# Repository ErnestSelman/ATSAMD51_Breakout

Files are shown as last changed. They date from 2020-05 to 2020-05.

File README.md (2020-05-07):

# ATSAMD51_Breakout
Similar to SparkFun Thing Plus but without battery charging and leaving USB and FLASH Memory in the same pins. All other pins are accessible. I also added a connector for the PICKit4.

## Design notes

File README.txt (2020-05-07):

Notes:
-Board Dimentions: 61.180 mm x 30.365 mm
-Drill sizes were chosen to be one of your free sizes, if any of them is not exactly one of the free sizes then it can be changed to nearest free size.
-PTH Holes sizes are finish hole sizes.

-Drill files:
	-drill_npth.xln
	-dril_pth.xln
-Gerber files included:
	-copper_bottom.gbr
	-copper_top.gbr
	-profile.gbr
	-silkscreen_top.gbr
	-soldermask_bottom.gbr
	-soldermask_top.gbr
-Aditional Files:
	-gerber_job.gbrjob
	-README.txt
	-SAMD51_Breakout.brd
	-SAMD51_Breakout.sch

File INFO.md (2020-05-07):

# ATSAMD51_Breakout
Similar to SparkFun Thing Plus but without battery charging and leaving USB and FLASH Memory in the same pins. All other pins are accessible. I also added a connector for the PICKit4 programmer/debugger. 
You could follow SparkFun Thing Plus tutorial and program their bootloader. It should work the same as theirs and you could use Arduino to program the board through the USB. Although the reason for making this board is to learn to work with low level CORTEX M4 and stop using Arduino.
Voltage regulator are more powerfull so you can power whatever else you want with the same board. There is no over-current protection so be very carefull. 
The Flash Memory IC has the same pin-out as the one in SparkFun Thin Plus so I connected it exactly the same. If you use the IC from the BoM, it might not be the same as the one used by SparkFun so their code could not work.

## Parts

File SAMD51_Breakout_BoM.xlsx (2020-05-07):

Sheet: Sheet1
Item # | Name | Part Description / Component Requirement | Digikey PN | Manufacturer | Manuf. PN | QTY | Unit Price | Price | Link
0 | PCB | PCB | n/a | elecrow | n/a | 1 | 5 | 5 | https://www.elecrow.com/pcb-manufacturing.html
1 | T1 | TERM BLOCK HDR 2POS 90DEG 3.5MM | 277-2416-ND | Phoenix Contact | 1844210 | 1 | 1.42 | 1.42 | https://www.digikey.com/products/en?keywords=277-2416-ND
2 | T2 | CONN HEADER R/A 10POS 2.54MM | 2057-PH1RB-10-UA-ND | Adam Tech | PH1RB-10-UA | 1 | 0.41 | 0.41 | https://www.digikey.com/products/en?keywords=2057-PH1RB-10-UA-ND
3 | T3, T4 | CONN HEADER VERT 24POS 2.54MM | S1131EC-24-ND | Sullins Connector Solutions | PRPC024SACN-RC | 2 | 1.1 | 2.2 | https://www.digikey.com/products/en?keywords=S1131EC-24-ND
4 | USB1 | CONN RCPT USB2.0 MICRO B SMD R/A | 609-4613-1-ND | Amphenol ICC (FCI) | 10118192-0001LF | 1 | 0.66 | 0.66 | https://www.digikey.com/products/en?keywords=609-4613-1-ND
5 | U1 | IC REG LINEAR 5V 1A SOT223 | NCP1117ST50T3GOSCT-ND | ON Semiconductor | NCP1117ST50T3G | 1 | 0.76 | 0.76 | https://www.digikey.com/products/en?keywords=NCP1117ST50T3GOSCT-ND
6 | U2 | IC REG LINEAR 3.3V 1.2A SOT223 | 497-17239-1-ND | STMicroelectronics | LDL1117S33R | 1 | 0.69 | 0.69 | https://www.digikey.com/products/en?keywords=497-17239-1-ND
7 | U3 | IC MCU 32BIT 1MB FLASH 64TQFP | ATSAMD51J20A-AU-ND | Microchip Technology | ATSAMD51J20A-AU | 1 | 7.89 | 7.89 | https://www.digikey.com/products/en?keywords=ATSAMD51J20A-AU-ND
8 | U4 | IC FLASH 4M SPI 104MHZ 8SOIC | W25X40CLSNIG-ND | Winbond Electronics | W25X40CLSNIG | 1 | 0.59 | 0.59 | https://www.digikey.com/products/en?keywords=W25X40CLSNIG-ND
9 | D1, D2 | DIODE SCHOTTKY 40V 1A SOD123 | 1N5819HW-FDICT-ND | Diodes Incorporated | 1N5819HW-7-F | 2 | 0.61 | 1.22 | https://www.digikey.com/products/en?keywords=1N5819HW-FDICT-ND
10 | V1, V2, V3, V4 | LED GREEN DIFFUSED 0603 SMD | 475-3118-1-ND | OSRAM Opto Semiconductors Inc. | LG L29K-F2J1-24-Z | 4 | 0.62 | 2.48 | https://www.digikey.com/products/en?keywords=475-3118-1-ND
11 | Y1 | CRYSTAL 32.768KHZ 12.5PF SMD | 2195-CM7V-T1A-32.768KHZ-12.5PF-20PPM-TA-QCCT-ND | Micro Crystal AG | CM7V-T1A-32.768KHZ-12.5PF-20PPM-TA-QC | 1 | 0.67 | 0.67 | https://www.digikey.com/products/en?keywords=2195-CM7V-T1A-32.768KHZ-12.5PF-20PPM-TA-QCCT-ND
12 | S1 | TACT 4.5 X 4.5, 3.8 MM H, 2.5N, | PTS647SK38SMTR2LFSCT-ND | C&K | PTS 647 SK38 SMTR2 LFS | 1 | 0.23 | 0.23 | https://www.digikey.com/products/en?keywords=PTS647SK38SMTR2LFSCT-ND
13 | L1, L2 | FIXED IND 10UH 150MA 360 MOHM | 587-2045-1-ND | Taiyo Yuden | LBR2012T100K | 2 | 0.21 | 0.42 | https://www.digikey.com/products/en?keywords=587-2045-1-ND
14 | C1 | CAP CER 22UF 25V X5R 0805 | 1276-2908-1-ND | Samsung Electro-Mechanics | CL21A226MAQNNNE | 1 | 0.8 | 0.8 | https://www.digikey.com/products/en?keywords=1276-2908-1-ND
15 | C2 | CAP CER 47UF 6.3V X5R 0805 | 490-9960-1-ND | Murata Electronics | GRM21BR60J476ME15L | 1 | 0.8 | 0.8 | https://www.digikey.com/products/en?keywords=490-9960-1-ND
16 | C3, C4 | CAP CER 15PF 50V C0G/NPO 0402 | 311-1642-1-ND | Yageo | CC0402FRNPO9BN150 | 2 | 0.18 | 0.36 | https://www.digikey.com/products/en?keywords=311-1642-1-ND
17 | C5,C6 | CAP CER 10UF 6.3V X5R 0805 | 1276-2405-1-ND | Samsung Electro-Mechanics | CL21A106KQCLRNC | 2 | 0.17 | 0.34 | https://www.digikey.com/products/en?keywords=1276-2405-1-ND
18 | C7, C8, C9, C10, C11, C13 | CAP CER 0.1UF 25V X7R 0603 | 311-1341-1-ND | Yageo | CC0603KRX7R8BB104 | 6 | 0.15 | 0.9 | https://www.digikey.com/products/en?keywords=311-1341-1-ND
19 | C12 | CAP CER 4.7UF 6.3V X5R 0603 | 1276-1045-1-ND | Samsung Electro-Mechanics | CL10A475KQ8NNNC | 1 | 0.15 | 0.15 | https://www.digikey.com/products/en?keywords=1276-1045-1-ND
20 | R1, R4, R5, R6, R7 | RES 820 OHM 1% 1/8W 0805 | RMCF0805FT820RCT-ND | Stackpole Electronics Inc | RMCF0805FT820R | 5 | 0.16 | 0.8 | https://www.digikey.com/products/en?keywords=RMCF0805FT820RCT-ND
21 | R2, R3 | RES SMD 10K OHM 1% 1/8W 0805 | 311-10.0KCRCT-ND | Yageo | RC0805FR-0710KL | 2 | 0.16 | 0.32 | https://www.digikey.com/products/en?keywords=311-10.0KCRCT-ND
22 |  |  |  |  |  |  |  | 0 | https://www.digikey.com/products/en?keywords=
 |  |  |  |  | Total | 40 | Total | 29.11

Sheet: Sheet2
Item | Index | Part Description / Component Requirement | Digikey PN | Manufacturer | Manuf. PN | USED QTY | Available | Order QTY | Unit Price | Total | Link
0 | PCB |  |  |  |  | 1 |  | 1 | 4 | 4
1 | T1 | CONN SOCKET 3POS 0.1 GOLD PCB | 1212-1090-ND | Preci-Dip | 310-87-103-41-001101 | 4 |  | 4 | 0.28 | 1.12 | https://www.digikey.com/products/en?keywords=310-87-103-41-001101
2 | T2,3 | CONN HEADER R/A 3x2POS 90Deg 2MM | H2866-ND | Hirose Electric Co Ltd | DF11-6DP-2DS(52) | 2 |  | 2 | 1.04 | 2.08 | https://www.digikey.com/products/en?keywords=DF11-6DP-2DS(52)
3 | U1 | TRANS NPN 60V 2A E-LINE | ZTX651-ND | Diodes Incorporated | ZTX651 | 1 |  | 1 | 0.87 | 0.87 | https://www.digikey.com/products/en?keywords=ZTX651
4 | U2,3,4,5 | IC INST AMP 1 CIRCUIT 8VSSOP | 296-41257-1-ND | Texas Instruments | INA126EA/2K5 | 4 |  | 4 | 3.08 | 12.32 | https://www.digikey.com/products/en?keywords=INA126EA/2K5
5 | U6 | IC OPAMP GP 1 CIRCUIT SOT23-5 | 296-44076-1-ND | Texas Instruments | OPA197IDBVT | 1 |  | 1 | 1.84 | 1.84 | https://www.digikey.com/products/en?keywords=OPA197IDBVT
6 | C1 | CAP CER 1UF 10V X7R 0805 | 1276-1275-1-ND | Samsung Electro-Mechanics | CL21B105KPFNNNE | 1 |  | 1 | 0.1 | 0.1 | https://www.digikey.com/products/en?keywords=CL21B105KPFNNNE
7 | C2,3 | CAP CER 100UF 16V X5R 1210 | 399-11270-1-ND | KEMET | C1210C107M4PAC7800 | 2 |  | 2 | 3.23 | 6.46 | https://www.digikey.com/products/en?keywords=C1210C107M4PAC7800
8 | C4 | CAP CER 0.1UF 25V X7R 0805 | 1276-1099-1-ND | Samsung Electro-Mechanics | CL21B104KACNNNC | 1 |  | 1 | 0.1 | 0.1 | https://www.digikey.com/products/en?keywords=CL21B104KACNNNC
9 | R1 | RES 0.33 OHM 1% 1W 2512 | 311-0.33TCT-ND | Yageo | RL2512FK-070R33L | 1 |  | 1 | 0.49 | 0.49 | https://www.digikey.com/products/en?keywords=RL2512FK-070R33L
10 | R2 | RES SMD 100 OHM 5% 1/8W 0805 | 311-100ARCT-ND | Yageo | RC0805JR-07100RL | 1 |  | 1 | 0.1 | 0.1 | https://www.digikey.com/products/en?keywords=RC0805JR-07100RL
11 | R3 | RES SMD 17.4K OHM 1% 1/8W 0805 | 311-17.4KCRCT-ND | Yageo | RC0805FR-0717K4L | 1 |  | 1 | 0.1 | 0.1 | https://www.digikey.com/products/en?keywords=RC0805FR-0717K4L
12 | R4,5,6,7 | RES SMD 150 OHM 1% 1/8W 0805 | 311-150CRCT-ND | Yageo | RC0805FR-07150RL | 4 |  | 4 | 0.1 | 0.4 | https://www.digikey.com/products/en?keywords=RC0805FR-07150RL
13 | R8,9,10,11,12,13,14,15 | RES SMD 1M OHM 1% 1/8W 0805 | 311-1.00MCRCT-ND | Yageo | RC0805FR-071ML | 8 |  | 8 | 0.1 | 0.8 | https://www.digikey.com/products/en?keywords=RC0805FR-071ML
14 |  |  |  |  |  |  |  | 0 |  | 0 | https://www.digikey.com/products/en?keywords=
15 |  |  |  |  |  |  |  | 0 |  | 0 | https://www.digikey.com/products/en?keywords=
16 |  |  |  |  |  |  |  | 0 |  | 0 | https://www.digikey.com/products/en?keywords=
17 |  |  |  |  |  |  |  | 0 |  | 0 | https://www.digikey.com/products/en?keywords=
18 |  |  |  |  |  |  |  | 0 |  | 0 | https://www.digikey.com/products/en?keywords=
 |  |  |  |  | Total | 32 |  |  | Total | 30.78

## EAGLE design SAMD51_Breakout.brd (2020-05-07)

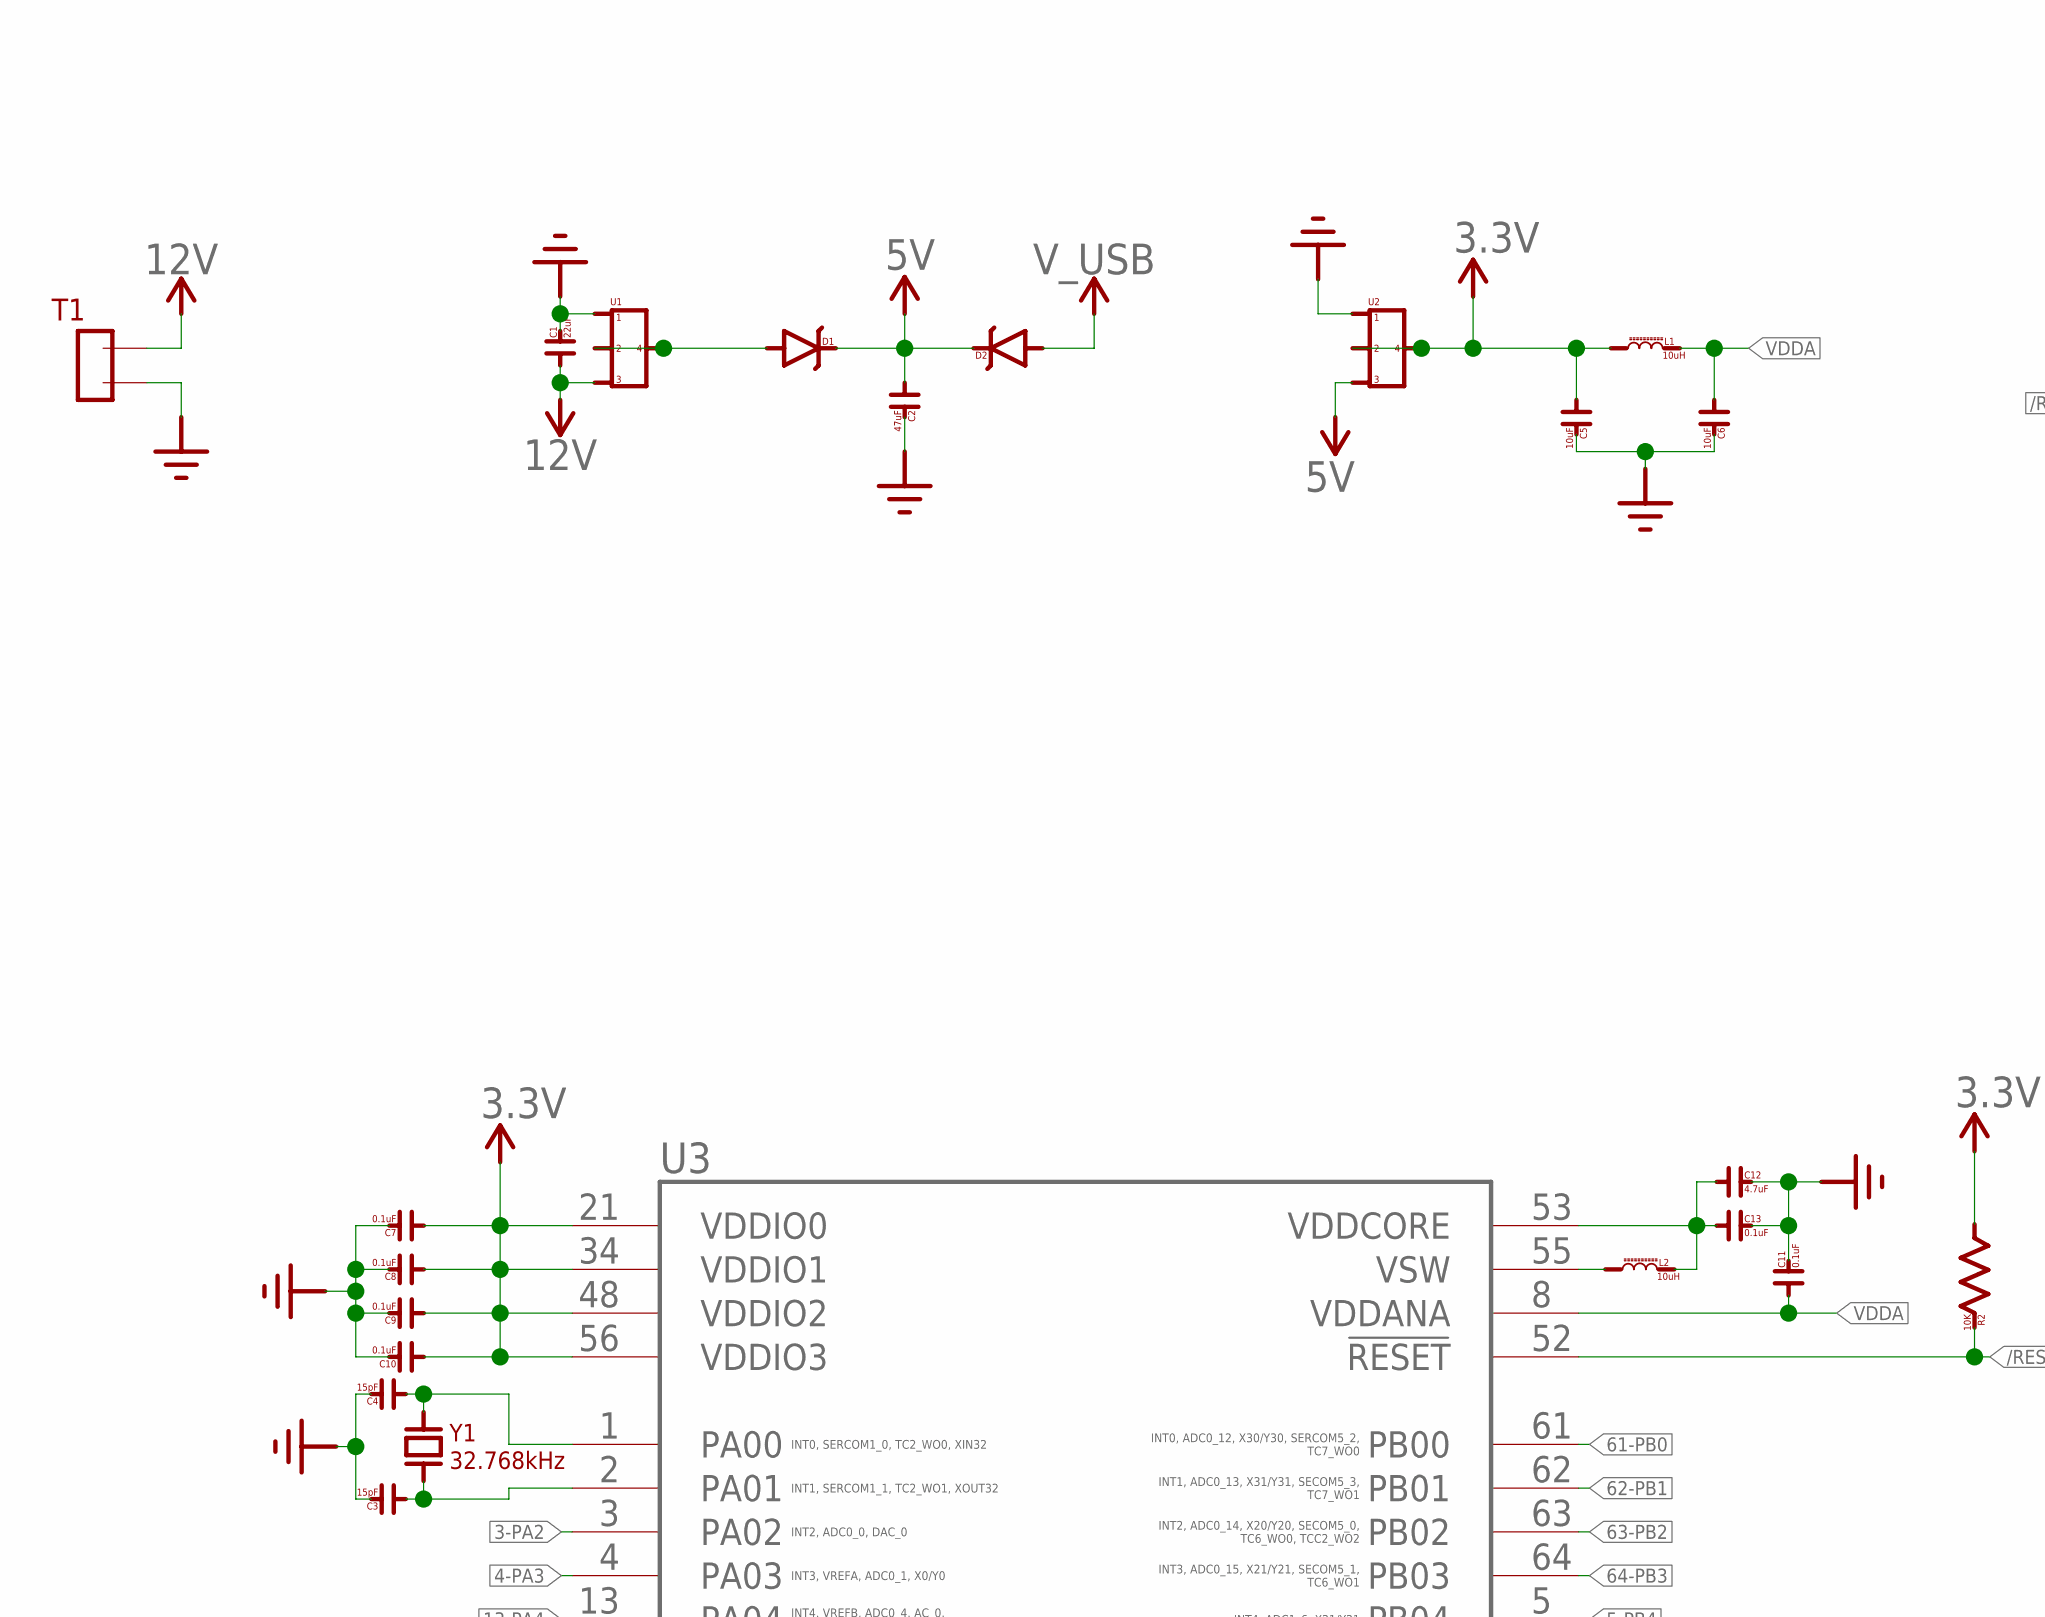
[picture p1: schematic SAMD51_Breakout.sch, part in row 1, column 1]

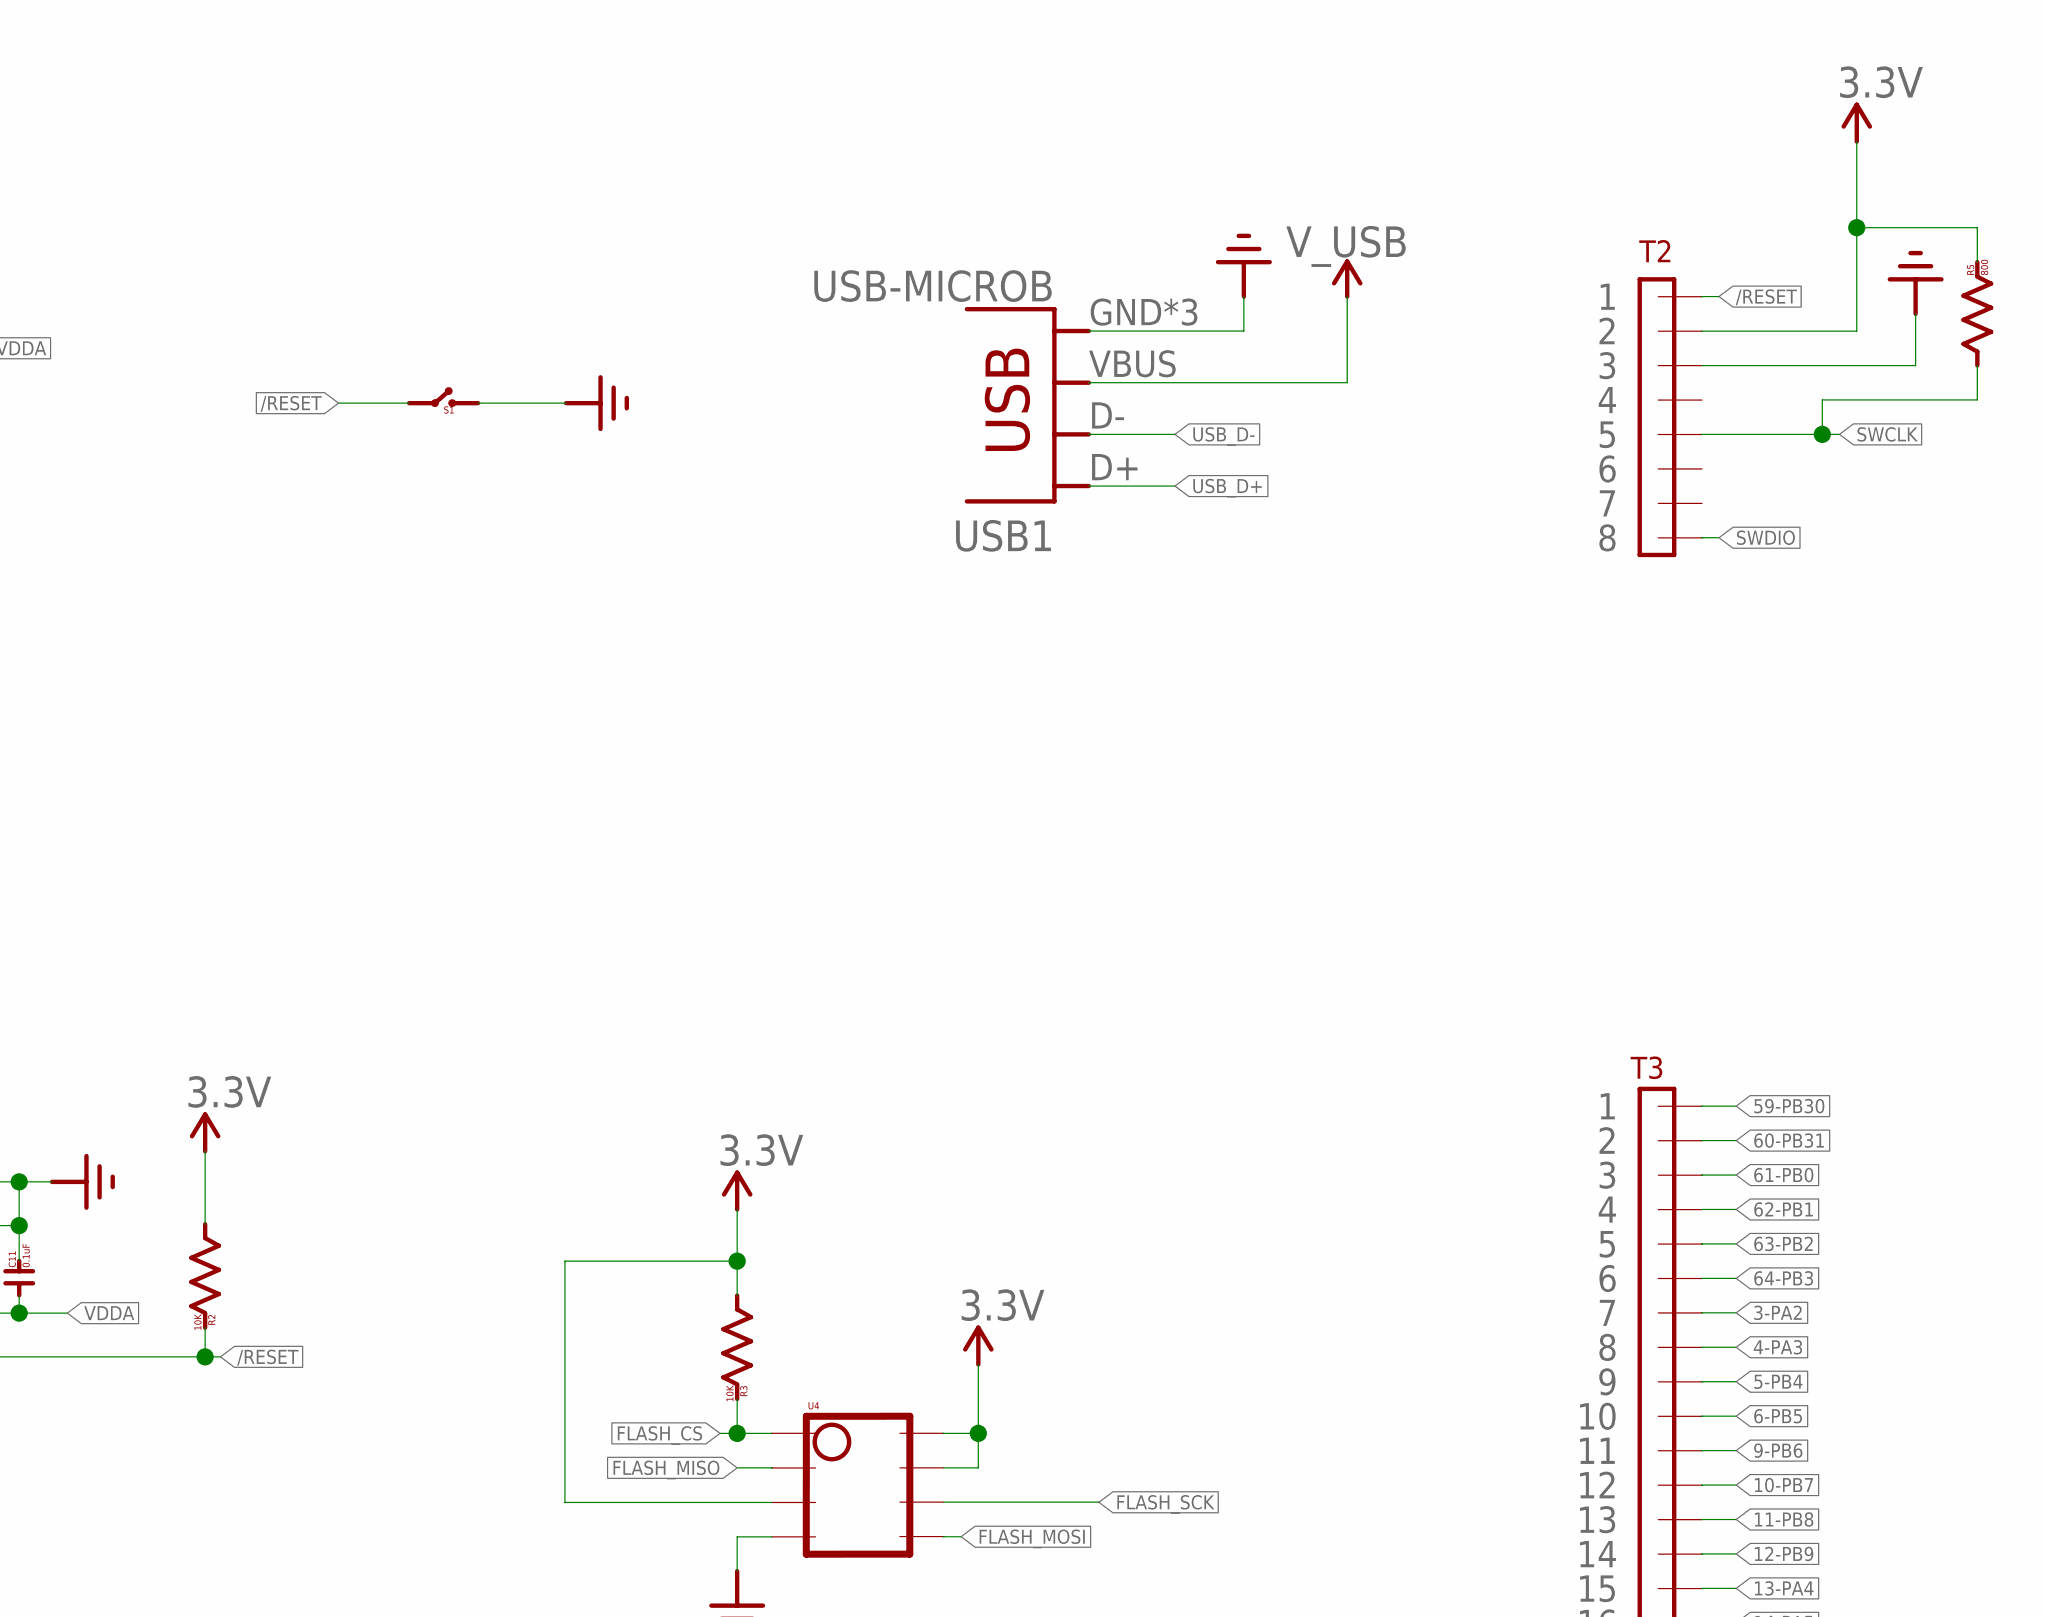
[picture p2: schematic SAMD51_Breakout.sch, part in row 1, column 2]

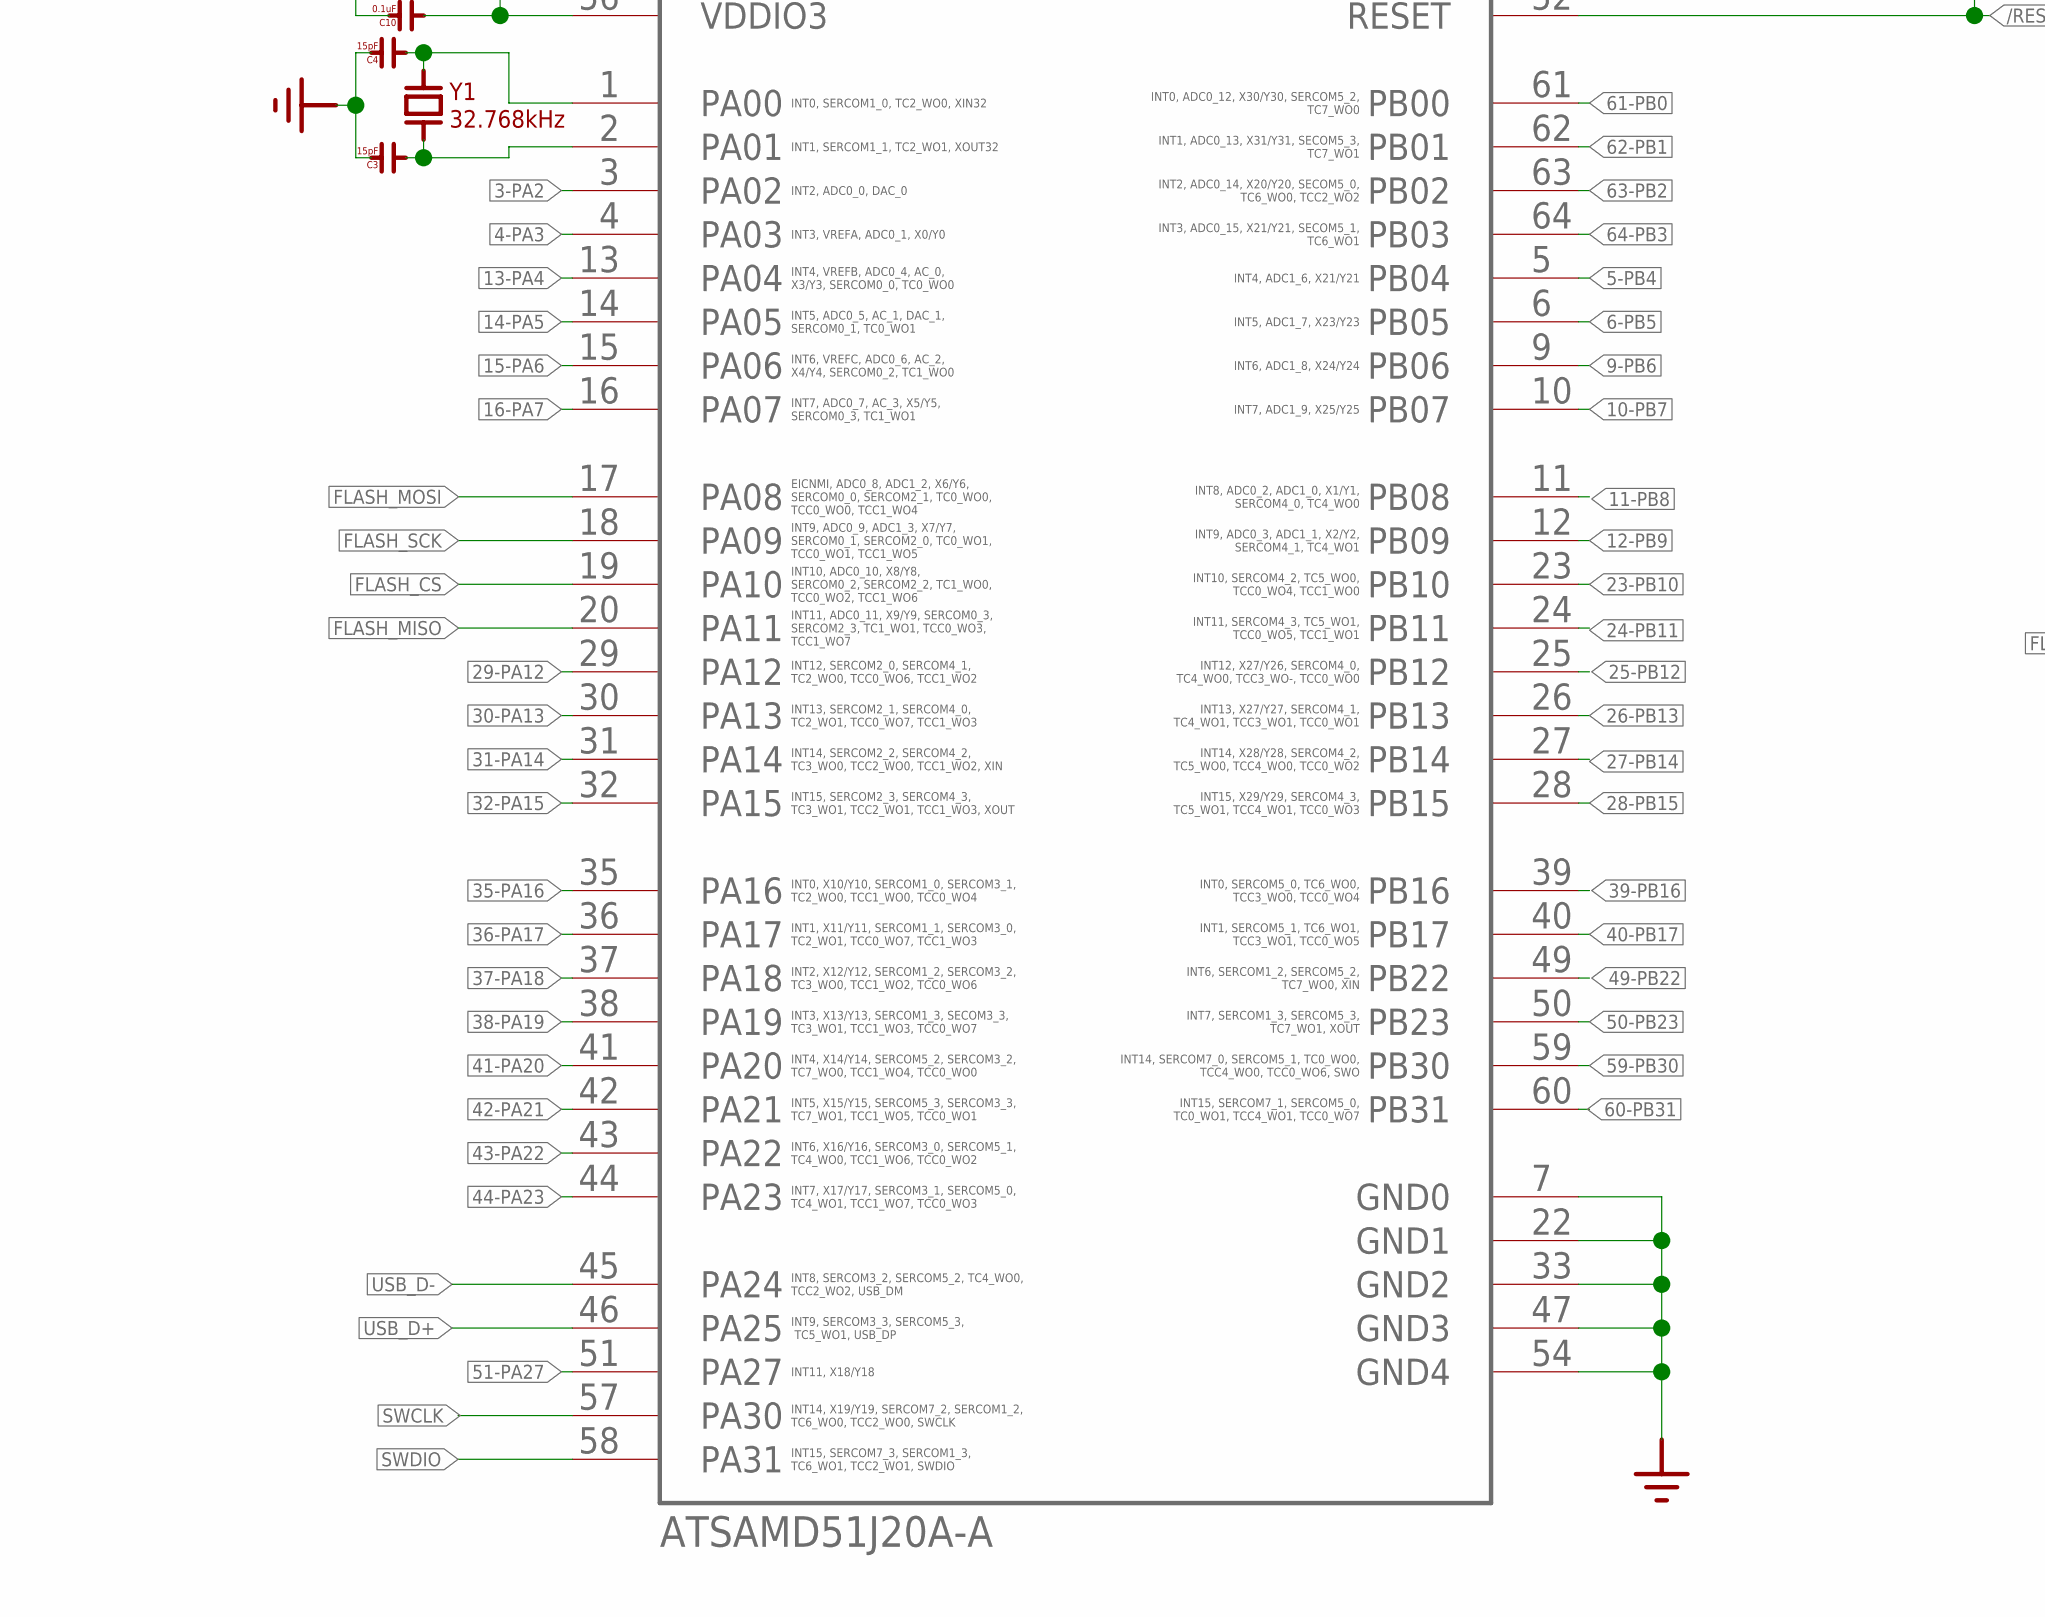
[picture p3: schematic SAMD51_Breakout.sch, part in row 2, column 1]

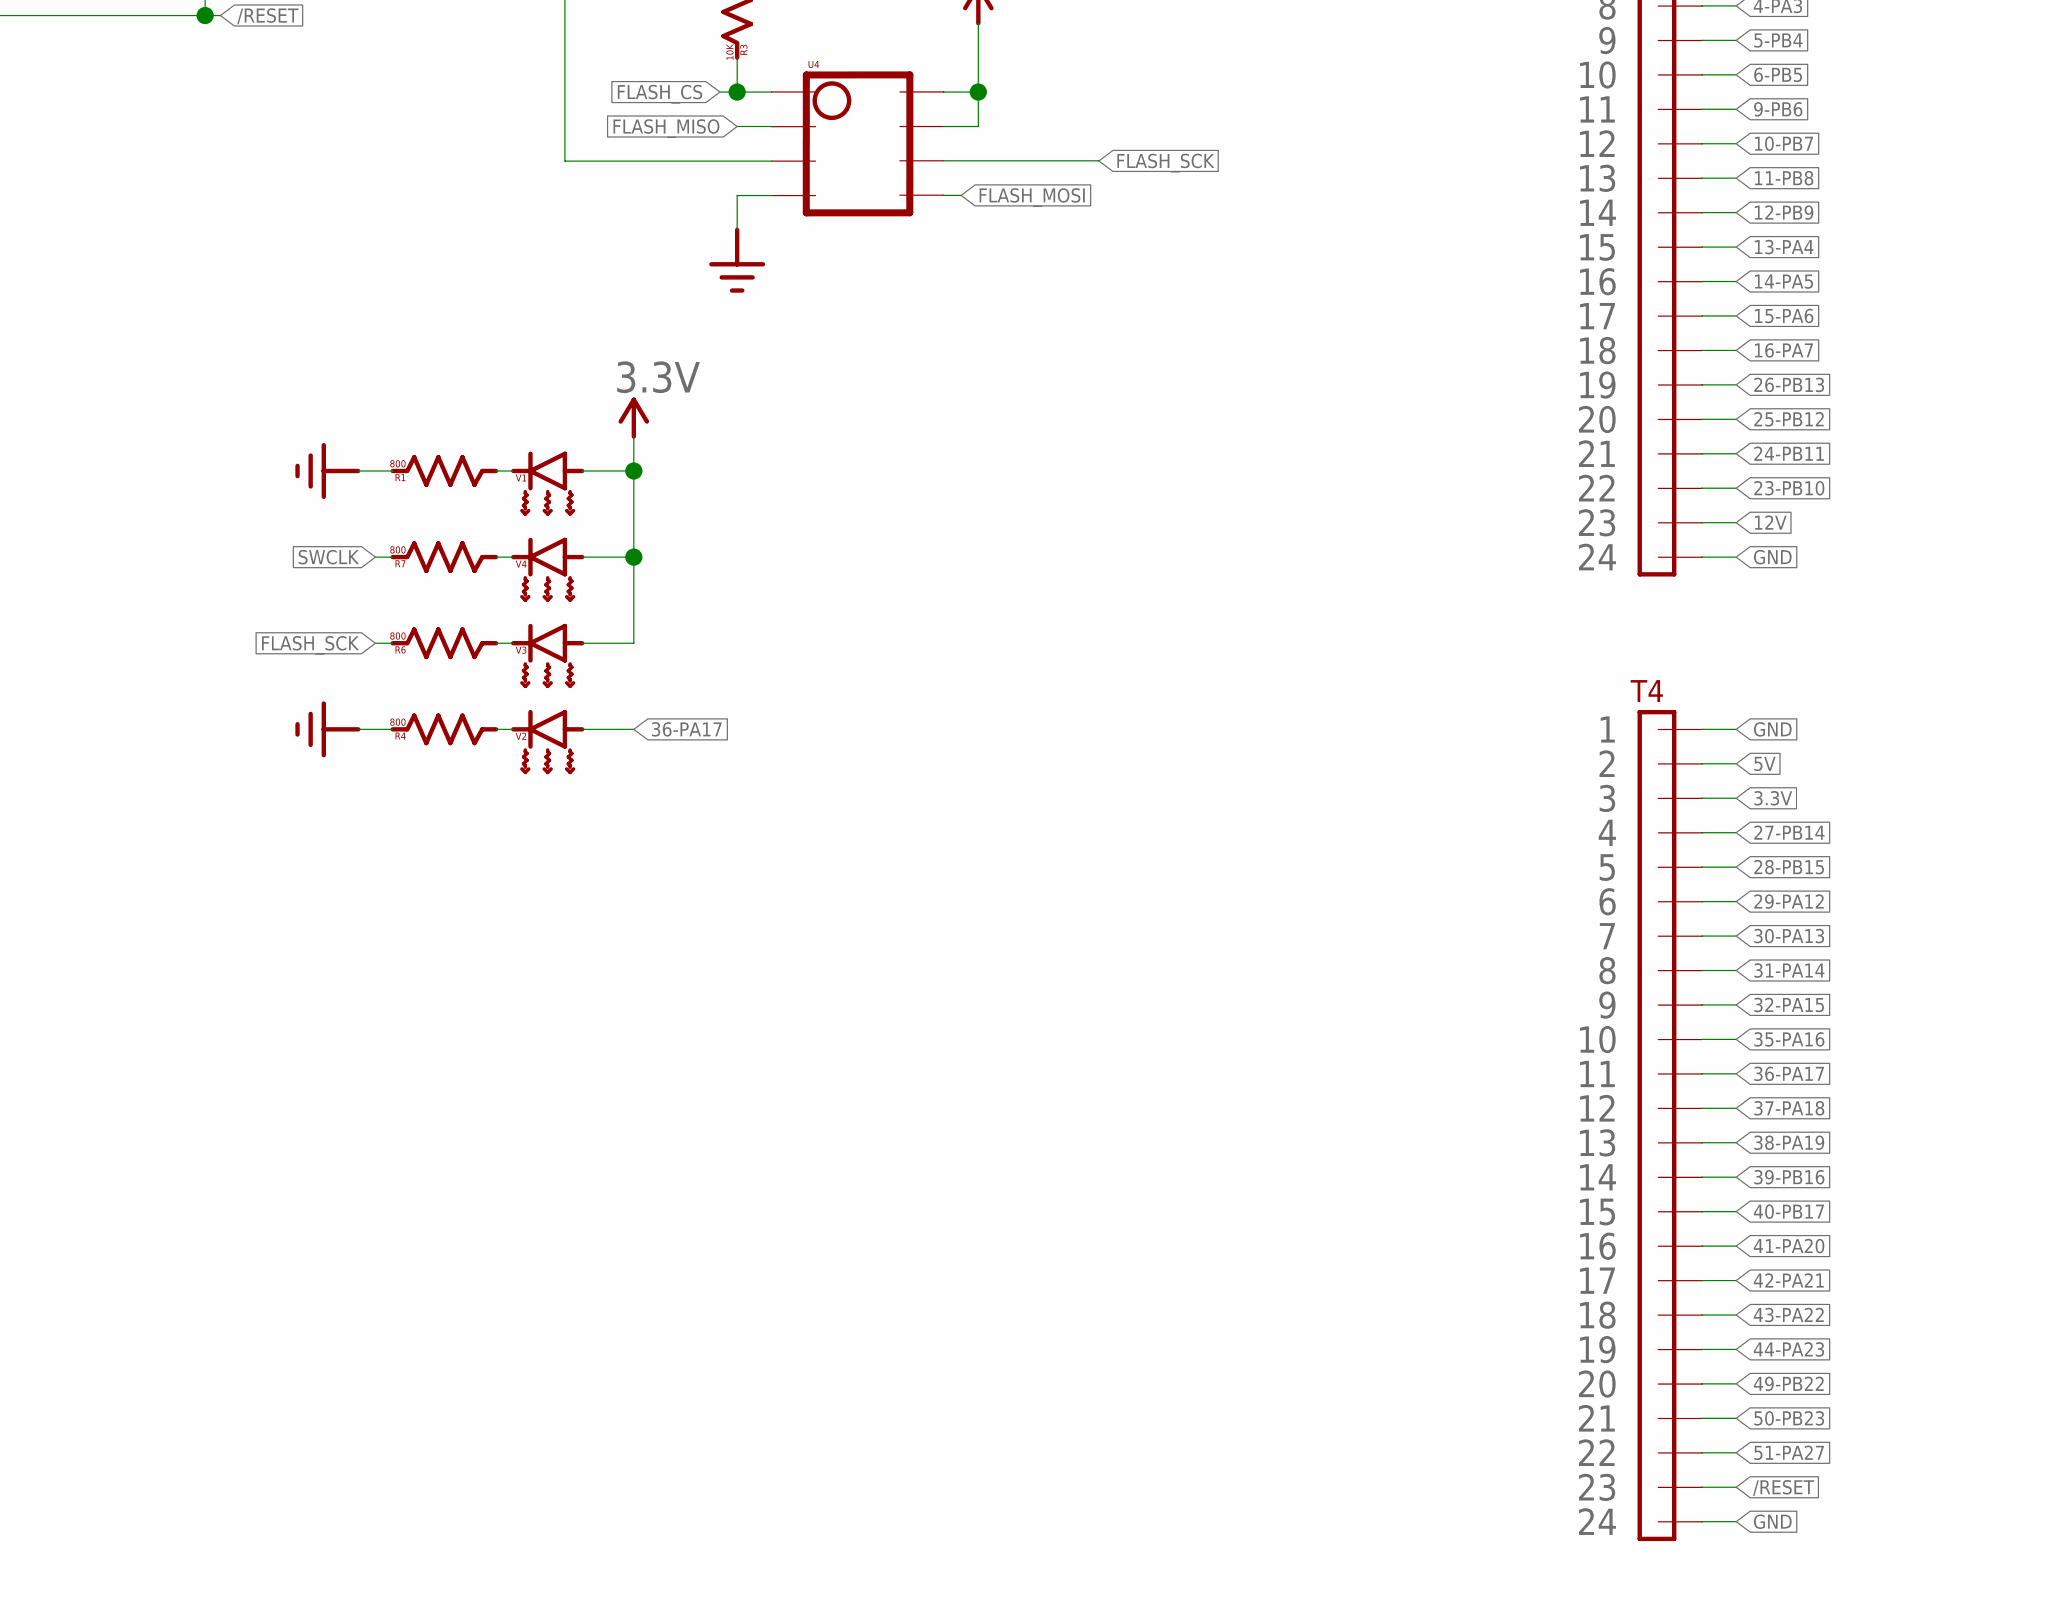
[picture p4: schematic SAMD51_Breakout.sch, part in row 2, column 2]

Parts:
C1: 22uF; 0805
C2: 47uF; 0805
C3, C4: 15pF; 0402
C5, C6: 10uF; 0805
C7, C8, C9, C10, C11, C13: 0.1uF; 0603
C12: 4.7uF; 0603
D1, D2: 1N5819_SMD
L1, L2: 10uH; 0805
R1, R4, R5, R6, R7: 800; 0805
R2, R3: 10K; 0805
S1: SWITCHPTS647; PTS647SK38SMTR2LFS
T1: PHEONIX_1844210
T2: 1X08_90DEG
T3, T4: 1X24
U1, U2: STANDARD_SOT223; SOT223
U3: ATSAMD51J20A-A; TQFP64
U4: SOIC8
USB1: USB-MICROB
V1, V2, V3, V4: LED_0603
Y1: 32.768kHz; CM7V-T1A

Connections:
3-PA2: T3.7, U3.3 (PA02)
3.3V: C5.1, C7.1, C8.1, C9.1, C10.1, L1.1, R2.1, R3.1, R5.2, T2.2, T4.3, U2.2, U2.4, U3.21 (VDDIO0), U3.34 (VDDIO1), U3.48 (VDDIO2), U3.56 (VDDIO3), U4.3, U4.7, U4.8, V1.1, V3.1, V4.1
4-PA3: T3.8, U3.4 (PA03)
5-PB4: T3.9, U3.5 (PB04)
5V: C2.1, D1.P$2, D2.P$2, T4.2, U2.3
6-PB5: T3.10, U3.6 (PB05)
9-PB6: T3.11, U3.9 (PB06)
10-PB7: T3.12, U3.10 (PB07)
11-PB8: T3.13, U3.11 (PB08)
12-PB9: T3.14, U3.12 (PB09)
12V: C1.1, T1.1, T3.23, U1.3
13-PA4: T3.15, U3.13 (PA04)
14-PA5: T3.16, U3.14 (PA05)
15-PA6: T3.17, U3.15 (PA06)
16-PA7: T3.18, U3.16 (PA07)
23-PB10: T3.22, U3.23 (PB10)
24-PB11: T3.21, U3.24 (PB11)
25-PB12: T3.20, U3.25 (PB12)
26-PB13: T3.19, U3.26 (PB13)
27-PB14: T4.4, U3.27 (PB14)
28-PB15: T4.5, U3.28 (PB15)
29-PA12: T4.6, U3.29 (PA12)
30-PA13: T4.7, U3.30 (PA13)
31-PA14: T4.8, U3.31 (PA14)
32-PA15: T4.9, U3.32 (PA15)
35-PA16: T4.10, U3.35 (PA16)
36-PA17: T4.11, U3.36 (PA17), V2.1
37-PA18: T4.12, U3.37 (PA18)
38-PA19: T4.13, U3.38 (PA19)
39-PB16: T4.14, U3.39 (PB16)
40-PB17: T4.15, U3.40 (PB17)
41-PA20: T4.16, U3.41 (PA20)
42-PA21: T4.17, U3.42 (PA21)
43-PA22: T4.18, U3.43 (PA22)
44-PA23: T4.19, U3.44 (PA23)
49-PB22: T4.20, U3.49 (PB22)
50-PB23: T4.21, U3.50 (PB23)
51-PA27: T4.22, U3.51 (PA27)
59-PB30: T3.1, U3.59 (PB30)
60-PB31: T3.2, U3.60 (PB31)
61-PB0: T3.3, U3.61 (PB00)
62-PB1: T3.4, U3.62 (PB01)
63-PB2: T3.5, U3.63 (PB02)
64-PB3: T3.6, U3.64 (PB03)
/RESET: R2.2, S1.P$1, S1.P$2, T2.1, T4.23, U3.52 (!RESET)
FLASH_CS: R3.2, U3.19 (PA10), U4.1
FLASH_MISO: U3.20 (PA11), U4.2
FLASH_MOSI: U3.17 (PA08), U4.5
FLASH_SCK: R6.2, U3.18 (PA09), U4.6
GND: C1.2, C2.2, C3.2, C4.2, C5.2, C6.2, C7.2, C8.2, C9.2, C10.2, C11.2, C12.2, C13.2, R1.2, R4.2, S1.P$3, S1.P$4, T1.2, T2.3, T3.24, T4.1, T4.24, U1.1, U2.1, U3.7 (GND0), U3.22 (GND1), U3.33 (GND2), U3.47 (GND3), U3.54 (GND4), U4.4, USB1.GND, USB1.MT1 (GND), USB1.MT2 (GND)
unnamed: R1.1, V1.2
unnamed: R4.1, V2.2
unnamed: C4.1, U3.1 (PA00), Y1.P$2
unnamed: D1.P$1, U1.2, U1.4
unnamed: C3.1, U3.2 (PA01), Y1.P$1
unnamed: R6.1, V3.2
unnamed: R7.1, V4.2
SWCLK: R5.1, R7.2, T2.5, U3.57 (PA30)
SWDIO: T2.8, U3.58 (PA31)
USB_D+: U3.46 (PA25), USB1.D+
USB_D-: U3.45 (PA24), USB1.D-
VDDA: C6.1, C11.1, L1.2, U3.8 (VDDANA)
VDDCORE: C12.1, C13.1, L2.2, U3.53 (VDDCORE)
VSW: L2.1, U3.55 (VSW)
V_USB: D2.P$1, USB1.VBUS

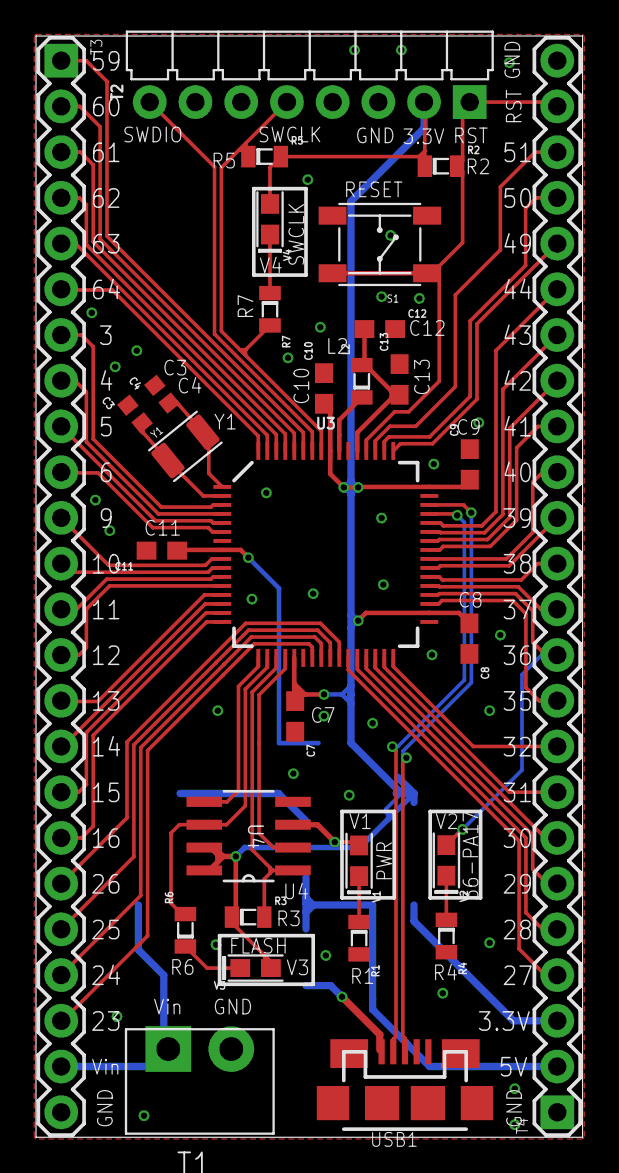
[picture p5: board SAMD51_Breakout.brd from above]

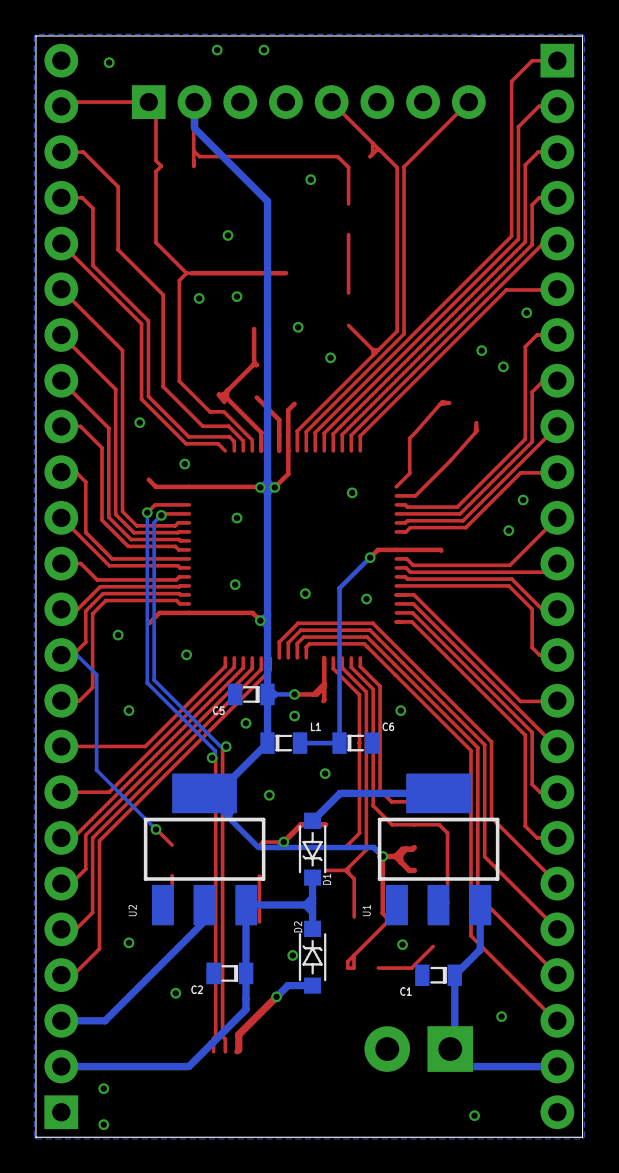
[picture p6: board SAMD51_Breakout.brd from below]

Board: 2 copper layers, 30.4 x 61.2 mm, 39 parts (9 on the bottom side), 65 nets.

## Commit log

2020-05-07 First commit, bringing all files into repo. Project was already done
    [SAMD51_Breakout.brd, SAMD51_Breakout.sch, SAMD51_Breakout_BoM.xlsx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]
2020-05-07 Fixing README and INFO. Adding BoM
    [SAMD51_Breakout_BoM.xlsx]

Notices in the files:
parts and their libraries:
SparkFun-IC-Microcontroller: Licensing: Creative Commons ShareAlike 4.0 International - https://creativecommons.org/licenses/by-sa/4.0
